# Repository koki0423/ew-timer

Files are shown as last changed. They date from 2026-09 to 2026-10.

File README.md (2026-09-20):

# timer

Arduino Nano を用いた 4 桁 7 セグメント表示付きタイマーの KiCad プロジェクトです。4 個の 4 ビット DIP スイッチで 16 ビットの設定値を入力し、開始/停止・リセット用の押しボタンで操作します。

このリポジトリには基板設計と製造データを収録しています。Arduino 用ファームウェア（`.ino` など）は含まれていません。

## 主な構成

| ブロック | 部品 | 役割 |
| --- | --- | --- |
| 制御 | A2: Arduino Nano v3.x | タイマー処理、表示走査、入力読取り |
| 表示 | U1: OSL-40391-LX | 4 桁・コモンカソードの 7 セグメント LED 表示器（コロン付き） |
| 表示駆動 | U2: 74HC595、R1-R8: 1 kΩ | シリアル出力を 8 本のセグメント信号（A-G、DP）へ展開。R1-R8 は各セグメントの電流制限抵抗 |
| 設定入力 | SW3-SW6: A7D-206-1、U3/U4: 74HC165、RN1-RN4: 10 kΩ | 4 個の 4 ビット DIP スイッチを 2 個の PISO シフトレジスタ経由で読み取る。各入力はプルダウンされ、スイッチ ON 時に High となる |
| 操作 | SW1、SW2 | リセット、開始/停止入力 |
| 状態表示 | U5: 74HC00、D1、R9: 300 Ω | DIP スイッチの一部を NAND 論理で判定し、エラー LED を点灯 |
| 電源安定化 | C1-C4: 0.1 µF | +5 V-GND 間のデカップリング |

基板外形は **120 mm × 90 mm**、板厚は **1.6 mm** です。表裏 2 層の配線を使用しています。

## Arduino Nano の接続

ファームウェアを作成する際は、以下の回路接続に合わせてピンを設定してください。

| Nano ピン | 接続先 | 用途 |
| --- | --- | --- |
| D2 | U2 SER (pin 14) | 7 セグメントのシリアルデータ |
| D3 | U2 RCLK (pin 12) | 74HC595 のラッチクロック |
| D4 | U2 SRCLK (pin 11) | 74HC595 のシフトクロック |
| D5 | U3/U4 `~PL` (pin 1) | DIP 入力のパラレルロード制御 |
| D6 | U3/U4 CP (pin 2) | DIP 入力のシフトクロック |
| D7 | U4 Q7 (pin 9) | 16 ビット DIP 入力のシリアル出力 |
| D9 | U1 DIG1 (pin 1) | 1 桁目の共通カソード選択 |
| D10 | U1 DIG2 (pin 2) | 2 桁目の共通カソード選択 |
| D11 | U1 DIG3 (pin 6) | 3 桁目の共通カソード選択 |
| D12 | U1 DIG4 (pin 8) | 4 桁目の共通カソード選択 |
| D13 | U1 COLON (pin 4) | コロン表示制御 |
| A0 | SW2 | 開始/停止ボタン。押下時は Low |
| A1 | SW1 | リセットボタン。押下時は Low |

U2 の出力は、`QA`-`QH` の順に `A`、`B`、`C`、`D`、`E`、`F`、`G`、`DP` セグメントへ接続されています。U3 の Q7 は U4 のシリアル入力へカスケード接続され、U4 の Q7 を Nano の D7 で読み取ります。

## 部品表

製造用の詳細 BOM は [production/bom.csv](production/bom.csv) を参照してください。主要部品は次のとおりです。

| 数量 | 部品 |
| ---: | --- |
| 1 | Arduino Nano v3.x |
| 1 | OSL-40391-LX 4 桁 7 セグメント LED 表示器 |
| 1 | 74HC595（DIP-16 ソケット） |
| 2 | 74HC165（DIP-16 ソケット） |
| 1 | 74HC00（DIP-14 ソケット） |
| 4 | A7D-206-1 4 ビット DIP スイッチ |
| 4 | 10 kΩ SIP 抵抗アレイ（5 ピン） |
| 8 | 1 kΩ 抵抗 |
| 1 | 300 Ω 抵抗 |
| 4 | 0.1 µF コンデンサ |
| 1 | 3 mm LED（エラー表示） |
| 2 | 12 mm タクトスイッチ |

## ファイル構成

| パス | 内容 |
| --- | --- |
| [timer.kicad_pro](timer.kicad_pro) | KiCad プロジェクト設定 |
| [timer.kicad_sch](timer.kicad_sch) | 回路図 |
| [timer.kicad_pcb](timer.kicad_pcb) | 基板レイアウト |
| [production/timer.zip](production/timer.zip) | 基板製造用 Gerber / ドリルデータ一式 |
| [production/bom.csv](production/bom.csv) | 製造・部品調達用 BOM |
| [production/positions.csv](production/positions.csv) | 部品実装座標 |
| [docs/](docs/) | 表示器、シフトレジスタ、DIP スイッチおよび LED ブラケットの資料 |

## 開き方と製造

1. KiCad で [timer.kicad_pro](timer.kicad_pro) を開きます。PCB ファイルは KiCad 10.0 形式です。
2. 回路図または基板を変更したら、ERC/DRC を実行してから製造データを再生成します。
3. 変更を加えず基板を発注する場合は、[production/timer.zip](production/timer.zip) を基板メーカーへアップロードします。
4. 実装には [production/bom.csv](production/bom.csv) と [production/positions.csv](production/positions.csv) を使用します。

## 注意事項

- `fp-lib-table` は A7D-206-1 用フットプリントについて、この PC 上の `C:/Users/koki/Downloads/...` を参照しています。このライブラリはリポジトリに含まれていないため、フットプリントを再割り当て・更新する場合は、同等のライブラリをローカルに追加して参照先を更新してください。
- U1 の回路図シンボルは OSL-40391-LX ですが、基板フットプリント名は `LTC-4627Jx` です。置換部品を選ぶ前に、同梱の [表示器データシート](docs/OSL40391-XX.pdf) でピン配列・極性・寸法を必ず照合してください。
- Nano の +5 V を基板全体の電源として使用します。USB 給電以外を用いる場合も、ロジック電源は +5 V、GND 共通にしてください。
- 7 セグメント表示は Nano による桁走査を想定しています。表示の極性、桁選択のタイミング、DIP スイッチのビット順は、実機で確認しながらファームウェア側で定義してください。

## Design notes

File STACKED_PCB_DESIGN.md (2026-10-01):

# Stacked PCB layout: initial placement

## Mechanical definition

- Both boards use the same **120 mm x 90 mm** outline.  This is within the
  requested maximum of 90 mm x 120 mm.
- Four aligned M3 plastic-screw clearance holes (3.2 mm NPTH) are at
  `(45, 55)`, `(155, 55)`, `(45, 135)`, and `(155, 135)` mm in KiCad board
  coordinates.  Each hole is 5 mm from its two nearest board edges.
- The lower board carries pin header `J1`; the upper board carries its mating
  socket `J1`.  Both are at `(52, 120)` and use a 2x6, 2.54 mm pitch pattern.

## Board partition

| Board | Contents |
| --- | --- |
| Upper / control | Arduino Nano A2, display U1, display driver U2 and R1-R8, SW1/SW2, error LED D1 with R9, buzzer, and the local reset/start-stop parts. |
| Lower / logic | Clock and debounce ICs U6-U8, input/error logic U3-U5, counters U9-U13, associated passives, and SW3-SW6 with RN1-RN4. |

The four user value selectors remain on the lower board.  They are aligned at
the accessible lower edge so they can be replaced by, or wired to, a thumb
rotary-switch header during the following routing stage.

## J1 pin assignment

| Pin | Net | Purpose |
| ---: | --- | --- |
| 1 | `/VCC` | +5 V supply |
| 2 | `GND` | Return |
| 3 | `/PL` | Parallel-load control |
| 4 | `/CP` | Shift clock |
| 5 | `/D5` | Arduino-to-logic signal |
| 6 | `/D8` | Arduino-to-logic signal |
| 7 | `/A1` | Debounced logic-to-Arduino signal |
| 8 | `reset_btn` | Reset button path |
| 9 | `start-stop_btn` | Start/stop button path |
| 10 | `GND` | Additional return |
| 11-12 | — | Reserved |

## Routing status

- The upper board was subsequently adjusted manually by the user.  It has not
  been changed or re-verified during the lower-board work.
- Lower board: the B.Cu GND plane was restored, connected with local solid
  plane connections where thermal spokes are constrained, and refilled.
- Lower board: all `/VCC` pads, the full J1 signal interface (including
  `/PL`), local clock/debounce links, the U3/U4/U9/U10/U11/U12 logic buses,
  555 branches, reset/start-stop paths, and SW3–SW6 selector wiring are
  routed.
- Final DRC after zone refill reports **0 unconnected items** and **0 errors**.
  The only remaining warnings are eight pre-existing local
  `lib_footprint_mismatch` notices (the four mounting holes, C12–C14, and J1).

The source `timer.kicad_pcb` remains unchanged.

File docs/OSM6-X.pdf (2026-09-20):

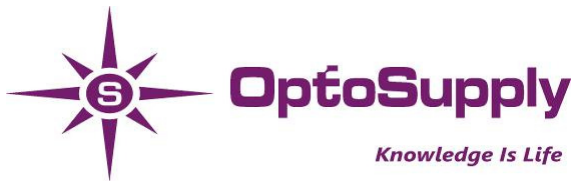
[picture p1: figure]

## 3mm LED Housing

Models | OSM6-X
Specification | Φ5.6*H9.2
Material | Plastic & Fe
Tolerance | ±0.3MM

### Product Picture Dimensions:

Model No. | OSM6-X
VER. | A.1.0

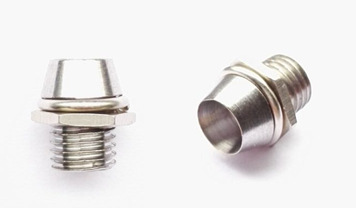
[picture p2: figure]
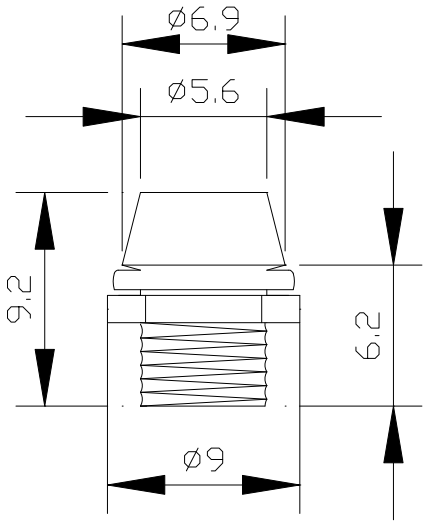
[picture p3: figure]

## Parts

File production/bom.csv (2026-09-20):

Designator | Footprint | Quantity | Value | LCSC Part #
A2 | Arduino_Nano | 1 | Arduino_Nano_v3.x
C1, C2, C3, C4 | C_Disc_D5.0mm_W2.5mm_P5.00mm | 4 | 0.1μF
D1 | LED_D3.0mm | 1 | error_LED
R1, R2, R3, R4, R5, R6, R7, R8 | R_Axial_DIN0207_L6.3mm_D2.5mm_P10.16mm_Horizontal | 8 | 1k
R9 | R_Axial_DIN0207_L6.3mm_D2.5mm_P10.16mm_Horizontal | 1 | 300
RN1, RN2, RN3, RN4 | R_Array_SIP5 | 4 | 10k
SW1 | SW_PUSH-12mm | 1 | reset_btn
SW2 | SW_PUSH-12mm | 1 | start_stop_btn
SW3, SW4, SW5, SW6 | A7D-206-1_OMR | 4 | A7D-206-1
U1 | LTC-4627Jx | 1 | OSL-40391-LX
U2 | DIP-16_W7.62mm_Socket | 1 | 74HC595
U3, U4 | DIP-16_W7.62mm_Socket | 2 | 74HC165
U5 | DIP-14_W7.62mm_Socket | 1 | 74HC00

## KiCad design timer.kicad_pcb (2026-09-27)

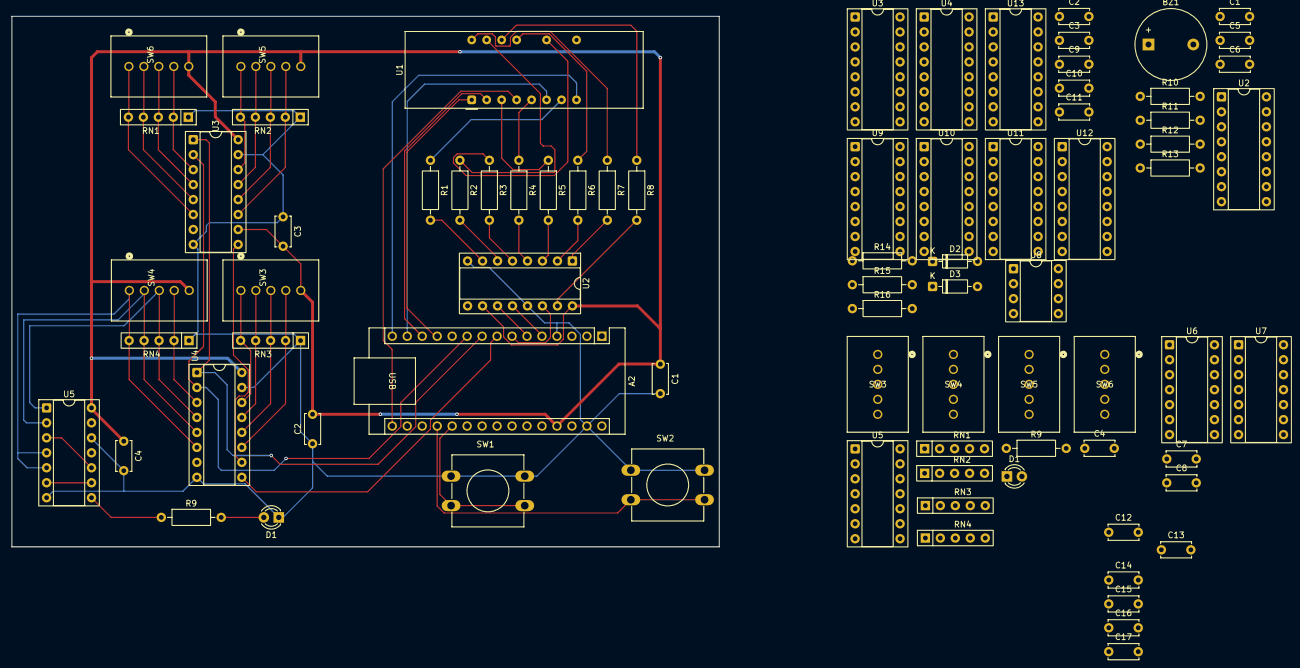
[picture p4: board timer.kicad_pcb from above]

Board: 2 copper layers, 120.0 x 90.0 mm, 79 parts (0 on the bottom side), 110 nets.

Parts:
A2: Arduino_Nano_R4; Arduino_Nano
BZ1: Buzzer; Buzzer_12x9.5RM7.6
C1, C2, C3, C4#2, C7, C8, C12, C13, C14, C15, C16, C17: 0.1u; C_Disc_D5.0mm_W2.5mm_P5.00mm
C1#2, C2#2, C3#2, C4: 0.1μF; C_Disc_D5.0mm_W2.5mm_P5.00mm
C5, C6: 1u; C_Disc_D5.0mm_W2.5mm_P5.00mm
C9: 4.7u; C_Disc_D5.0mm_W2.5mm_P5.00mm
C10: 0.01u; C_Disc_D5.0mm_W2.5mm_P5.00mm
C11: 10n; C_Disc_D5.0mm_W2.5mm_P5.00mm
D1, D1#2: error_LED; LED_D3.0mm
D2, D3: 1SS106; D_DO-35_SOD27_P7.62mm_Horizontal
R1, R2, R3, R4, R5, R6, R7, R8, R16: 1k; R_Axial_DIN0207_L6.3mm_D2.5mm_P10.16mm_Horizontal
R9, R9#2: 300; R_Axial_DIN0207_L6.3mm_D2.5mm_P10.16mm_Horizontal
R10, R11, R12, R13: 10k; R_Axial_DIN0207_L6.3mm_D2.5mm_P10.16mm_Horizontal
R14, R15: 100k; R_Axial_DIN0207_L6.3mm_D2.5mm_P10.16mm_Horizontal
RN1, RN1#2, RN2, RN2#2, RN3, RN3#2, RN4, RN4#2: 10k; R_Array_SIP5
SW1: reset_btn; SW_PUSH-12mm
SW2: start_stop_btn; SW_PUSH-12mm
SW3, SW3#2, SW4, SW4#2, SW5, SW5#2, SW6, SW6#2: A7D-206-1; A7D-206-1_OMR
U1: OSL-40391-LX; LTC-4627Jx
U2, U2#2: 74HC595; DIP-16_W7.62mm_Socket
U3, U3#2, U4, U4#2: 74HC165; DIP-16_W7.62mm_Socket
U5, U5#2: 74HC00; DIP-14_W7.62mm_Socket
U6: 74HC14; DIP-14_W7.62mm_Socket
U7: 74HC74; DIP-14_W7.62mm_Socket
U8: NE555D; DIP-8_W7.62mm_Socket
U9, U10, U11, U12: 74HC192; DIP-16_W7.62mm_Socket
U13: 74HC157; DIP-16_W7.62mm_Socket

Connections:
/1Hz発振回路/HC14-in: C11.2, R16.1, U6.13
/1Hz発振回路/HC14-out: D2.2 (A), U6.6
/1Hz発振回路/QA-D0-m: U3.11 (D0), U10.3 (QA)
/1Hz発振回路/QA-D0-s: U4#2.11 (D0), U12.3 (QA)
/1Hz発振回路/QA-D4-m: U3.3 (D4), U9.3 (QA)
/1Hz発振回路/QA-D4-s: U4#2.3 (D4), U11.3 (QA)
/1Hz発振回路/QB-D1-m: U3.12 (D1), U10.2 (QB)
/1Hz発振回路/QB-D1-s: U4#2.12 (D1), U12.2 (QB)
/1Hz発振回路/QB-D5-m: U3.4 (D5), U9.2 (QB)
/1Hz発振回路/QB-D5-s: U4#2.4 (D5), U11.2 (QB)
/1Hz発振回路/QC-D2-m: U3.13 (D2), U10.6 (QC)
/1Hz発振回路/QC-D2-s: U4#2.13 (D2), U12.6 (QC)
/1Hz発振回路/QC-D6-m: U3.5 (D6), U9.6 (QC)
/1Hz発振回路/QC-D6-s: U4#2.5 (D6), U11.6 (QC)
/1Hz発振回路/QD-D3-m: U3.14 (D3), U10.7 (QD)
/1Hz発振回路/QD-D3-s: U4#2.14 (D3), U12.7 (QD)
/1Hz発振回路/QD-D7-m: U3.6 (D7), U9.7 (QD)
/1Hz発振回路/QD-D7-s: U4#2.6 (D7), U11.7 (QD)
/1Hz発振回路/clk_out: U8.3 (OUT), U12.4 (DOWN)
/A1: A2.20 (A1), U7.5 (Q)
/CP: A2.10 (D7), U3.2 (CP), U4#2.2 (CP)
/D2: A2.5 (D2), U2#2.12 (RCLK)
/D3: A2.6 (D3), U2#2.11 (SRCLK)
/D4: A2.7 (D4), U2#2.14 (SER)
/D5: A2.8 (D5), U4#2.9 (Q7)
/D8: A2.11 (D8), R9.1, U5.8
/PL: A2.9 (D6), U3.1 (~PL), U4#2.1 (~PL)
/VCC: A2.27 (+5V), C1.1, C2.2, C3.2, C4#2.1, C7.2, C8.1, C12.2, C13.2, C14.2, C15.2, C16.1, C17.2, R10.1, R12.1, R15.1, SW3.C, SW4.C, SW5.C, SW6#2.C, U2#2.16 (VCC), U3.10 (DS), U3.16 (VCC), U4#2.16 (VCC), U5.14 (VCC), U6.14 (VCC), U7.4 (~S), U7.10 (~S), U7.14 (VCC), U8.8 (VCC), U9.5 (UP), U9.16 (VCC), U10.5 (UP), U10.16 (VCC), U11.5 (UP), U11.16 (VCC), U12.5 (UP), U12.16 (VCC), U13.2 (1A), U13.11 (3A), U13.16 (VCC)
GND: A2.4 (GND), A2.29 (GND), BZ1.2 (-), C1.2, C1#2.2, C2.1, C2#2.1, C3.1, C3#2.1, C4.2, C4#2.2, C5.1, C6.1, C7.1, C8.2, C9.1, C10.2, C11.1, C12.1, C13.1, C14.1, C15.1, C16.2, C17.1, D1.1 (K), D1#2.1 (K), RN1.1 (common), RN1#2.1 (common), RN2.1 (common), RN2#2.1 (common), RN3.1 (common), RN3#2.1 (common), RN4.1 (common), RN4#2.1 (common), SW1.1, SW2.1, U2.8 (GND), U2.13 (~OE), U2#2.8 (GND), U2#2.13 (~OE), U3.8 (GND), U3.15 (~CE), U3#2.8 (GND), U3#2.15 (~CE), U4.8 (GND), U4.15 (~CE), U4#2.8 (GND), U4#2.15 (~CE), U5.7 (GND), U5.12, U5.13, U5#2.7 (GND), U5#2.12, U5#2.13, U6.7 (GND), U6.9, U6.11, U7.7 (GND), U7.11 (C), U7.13 (~R), U8.1 (GND), U9.8 (GND), U9.14 (CLR), U10.8 (GND), U10.14 (CLR), U11.8 (GND), U11.14 (CLR), U12.8 (GND), U12.14 (CLR), U13.5 (2A), U13.8 (GND), U13.14 (4A), U13.15 (~ST)
unnamed: C1#2.1, C2#2.2, C3#2.2, C4.1, SW3#2.C, SW4#2.C, SW5#2.C, SW6.C, U2.10 (~SRCLR), U2.16 (VCC), U3#2.10 (DS), U3#2.16 (VCC), U4.16 (VCC), U5#2.14 (VCC)
unnamed: A2.26 (A7), BZ1.1 (+)
unnamed: U3#2.1 (~PL), U4.1 (~PL)
unnamed: U3#2.2 (CP), U4.2 (CP)
unnamed: A2.12 (D9), U1.1 (DIG1)
unnamed: A2.13 (D10), U1.2 (DIG2)
unnamed: A2.14 (D11), U1.6 (DIG3)
unnamed: A2.15 (D12), U1.8 (DIG4)
unnamed: A2.16 (D13), U1.4 (COLON)
unnamed: D1.2 (A), D1#2.2 (A), R9.2, R9#2.2
unnamed: D2.1 (K), D3.1 (K), U11.11 (~LOAD)
unnamed: R9#2.1, U5#2.8
unnamed: R10.2, R11.1, SW2.2
unnamed: R12.2, R13.1, SW1.2
unnamed: RN1.2 (R1), SW6.1, U3#2.3 (D4)
unnamed: RN1.3 (R2), SW6.2, U3#2.4 (D5)
unnamed: RN1.4 (R3), SW6.4, U3#2.5 (D6)
unnamed: RN1.5 (R4), SW6.8, U3#2.6 (D7)
unnamed: RN2.2 (R1), SW5#2.1, U3#2.11 (D0)
unnamed: RN2.3 (R2), SW5#2.2, U3#2.12 (D1)
unnamed: RN2.4 (R3), SW5#2.4, U3#2.13 (D2)
unnamed: RN2.5 (R4), SW5#2.8, U3#2.14 (D3)
unnamed: RN3.2 (R1), SW3#2.1, U4.11 (D0)
unnamed: RN3.3 (R2), SW3#2.2, U4.12 (D1)
unnamed: RN3.4 (R3), SW3#2.4, U4.13 (D2)
unnamed: RN3.5 (R4), SW3#2.8, U4.14 (D3)
unnamed: RN4.2 (R1), SW4#2.1, U4.3 (D4)
unnamed: RN4.3 (R2), SW4#2.2, U4.4 (D5), U5#2.1
unnamed: RN4.4 (R3), SW4#2.4, U4.5 (D6), U5#2.2
unnamed: RN4.5 (R4), SW4#2.8, U4.6 (D7), U5#2.4, U5#2.5
unnamed: R8.1, U1.14 (A)
unnamed: R7.1, U1.16 (B)
unnamed: R6.1, U1.13 (C)
unnamed: R5.1, U1.3 (D)
unnamed: R1.1, U1.7 (DP)
unnamed: R4.1, U1.5 (E)
unnamed: R3.1, U1.11 (F)
unnamed: R2.1, U1.15 (G)
unnamed: R8.2, U2.15 (QA), U2#2.15 (QA)
unnamed: R7.2, U2.1 (QB), U2#2.1 (QB)
unnamed: R6.2, U2.2 (QC), U2#2.2 (QC)
unnamed: R5.2, U2.3 (QD), U2#2.3 (QD)
unnamed: R4.2, U2.4 (QE), U2#2.4 (QE)
unnamed: R3.2, U2.5 (QF), U2#2.5 (QF)
unnamed: R2.2, U2.6 (QG), U2#2.6 (QG)
unnamed: R1.2, U2.7 (QH), U2#2.7 (QH)
unnamed: U3.9 (Q7), U3#2.9 (Q7), U4.10 (DS), U4#2.10 (DS)
unnamed: U5.6, U5.9, U5#2.6, U5#2.9
unnamed: U5.3, U5.10, U5#2.3, U5#2.10
unnamed: U6.5, U6.12
unnamed: U6.2, U7.3 (C)
unnamed: U7.2 (D), U7.6 (~Q)
unnamed: U6.4, U7.1 (~R)
unnamed: C10.1, U8.5 (CONT)
unnamed: R14.1, R15.2, U8.7 (DISCH)
unnamed: C9.2, R14.2, U8.2 (TRIG), U8.6 (THRES)
unnamed: R16.2, U10.4 (DOWN), U11.13 (~BO)
unnamed: U9.4 (DOWN), U10.13 (~BO)
unnamed: U11.15 (A), U13.4 (1Y)
unnamed: U11.1 (B), U13.7 (2Y)
unnamed: U11.10 (C), U13.9 (3Y)
unnamed: U11.9 (D), U13.12 (4Y)
unnamed: U11.4 (DOWN), U12.13 (~BO), U13.1 (SELECT)
SW3_1: RN3#2.2 (R1), SW3.1, U12.15 (A)
SW3_2: RN3#2.3 (R2), SW3.2, U12.1 (B)
SW3_4: RN3#2.4 (R3), SW3.4, U12.10 (C)
SW3_8: RN3#2.5 (R4), SW3.8, U12.9 (D)
SW4_1: RN4#2.2 (R1), SW4.1, U13.3 (1B)
SW4_2: RN4#2.3 (R2), SW4.2, U5.1, U13.6 (2B)
SW4_4: RN4#2.4 (R3), SW4.4, U5.2, U13.10 (3B)
SW4_8: RN4#2.5 (R4), SW4.8, U5.4, U5.5, U13.13 (4B)
SW5_1: RN2#2.2 (R1), SW5.1, U10.15 (A)
SW5_2: RN2#2.3 (R2), SW5.2, U10.1 (B)
SW5_4: RN2#2.4 (R3), SW5.4, U10.10 (C)
SW5_8: RN2#2.5 (R4), SW5.8, U10.9 (D)
SW6_1: RN1#2.2 (R1), SW6#2.1, U9.15 (A)
SW6_2: RN1#2.3 (R2), SW6#2.2, U9.1 (B)
SW6_4: RN1#2.4 (R3), SW6#2.4, U9.10 (C)
SW6_8: RN1#2.5 (R4), SW6#2.8, U9.9 (D)
reset_btn: C6.2, D3.2 (A), R13.2, U6.3, U9.11 (~LOAD), U10.11 (~LOAD), U12.11 (~LOAD)
start-stop_btn: C5.2, R11.2, U6.1, U8.4 (~RST)

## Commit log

2026-09-20 feat: タクトスイッチのデバウンスとタイマー状態保持回路を追加
    [timer.kicad_sch]
2026-09-20 feat: ブザーを追加
    [timer.kicad_sch]
2026-09-27 feat: クロック・カウンタ回路を追加
    [clock.kicad_sch, debounce.kicad_sch, inout.kicad_sch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]
2026-09-27 feat: クロック回路にデカップリングコンデンサを追加
    [clock.kicad_sch, timer.kicad_pcb, timer.kicad_sch]
2026-10-01 feat: 下層ロジック基板の配線を追加
    [timer_lower.kicad_pcb]
